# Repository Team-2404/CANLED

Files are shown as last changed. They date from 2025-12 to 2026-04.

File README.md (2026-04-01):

# CANLED
*An open source CAN LED controller for FRC*




> [!NOTE]
> Picture TBD

## Overview

CANLED is an open source LED controller by FRC team 2404 which communicates over the 
CAN protocol. Based on the ATmega328P microcontroller and MCP2515/2561 CAN 
controller/transciever, this project repository includes the parts (`hardware/docs/`),
schematics (`hardware/kicad/`), firmware (`firmware/canled/`), and software (`software/`) 
needed to assemble the controller and use it with wpilib for FRC. By default set up to control LED strips using the WS2812B controller.

An AVR programmer is needed to flash the firmware using the Arduino IDE.

## Flashing firmware

These instructions assume you are using Windows and a generic USBasp AVR programmer such as [this](https://www.amazon.com/HiLetgo-ATMEGA8-Programmer-USBasp-Cable/dp/B00AX4WQ00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). 
First, [install zadig.exe](https://zadig.akeo.ie/). Plug in your programmer, connect the CANLED,
and open zadig. Find the USBasp device in the drop-down menu and select it. Choose the WinUSB driver
on the right side using the arrows and click install. Once the driver is installed, open Arduino IDE.
Open up the canled.ino file in the firmware directory (`firmware/canled`) and open up the "tools" 
drop-down menu. Select Arduino Uno as the board and USBasp as the programmer. Open up the "sketch" 
drop-down menu and select "install using programmer". If there is an error, try unplugging and 
replugging the programmer. 

## Contributors

- @ConorKellyGerakos
- @koshan-dawlaty
- @jakehlee (mentor)

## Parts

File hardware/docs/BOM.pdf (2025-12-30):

Index Manufacturer Name | Description | Manufacturer Part Number Digi-Key Part Number | Quantity
1 Traco Power | DC DC CONVERTER 5V 5W | TSR 1-2450 | 1951-2747-ND | 1
2 Microchip Technology | IC TRANSCEIVER HALF 1/1 8PDIP | MCP2561-H/P | MCP2561-H/P-ND | 1
3 Microchip Technology | IC MCU 8BIT 32KB FLASH 28DIP | ATMEGA328-PU | ATMEGA328-PU-ND | 1
4 Microchip Technology | IC CAN CONTROLLER W/SPI 18DIP | MCP2515-I/P | MCP2515-I/P-ND | 1
5 STMicroelectronics | DIODE SCHOTTKY 30V 1A DO41 | 1N5818 | 497-4548-1-ND | 1
6 Rubycon | CAP ALUM 1000UF 20% 16V RADIAL | 16ZLH1000MEFC10X16 | 1189-1147-ND | 1
7 Würth Elektronik | CONN HEADER VERT 6POS 2.54MM | 61200621621 | 732-5394-ND | 1
8 TE Connectivity AMP Connectors | CONN IC DIP SOCKET 8POS TIN | 1-2199298-2 | A120347-ND | 1
9 TE Connectivity AMP Connectors | CONN IC DIP SOCKET 28POS TIN | 1-2199298-9 | A120353-ND | 1
10 Raltron Electronics | CRYSTAL 16.0000MHZ 18PF TH | AS-16.000-18 | 2151-AS-16.000-18-ND | 1
11 WAGO Corporation | PCB TERMINAL BLOCK; LEVER; 4 MM; | 2604-1103 | 2946-2604-1103-ND | 3
12 WAGO Corporation | PCB TERMINAL BLOCK; LEVER; 4 MM; | 2604-1104 | 2946-2604-1104-ND | 1
13 CNC Tech | CONN IC DIP SOCKET 18POS TIN | 245-18-1-03 | 1175-1489-ND | 1
14 Vishay Beyschlag/Draloric/BC Components CAP CER 0.1UF 50V X7R RADIAL | K104K10X7RF5UH5 | BC2665CT-ND | 4
15 Vishay Beyschlag/Draloric/BC Components CAP CER 1UF 50V X7R RADIAL | K105K20X7RF5UH5 | BC2668CT-ND | 2
16 Vishay Beyschlag/Draloric/BC Components CAP CER 22PF 50V C0G/NP0 RADIAL | K220J10C0GF5UH5 | BC5230CT-ND | 4
17 Citizen Finedevice Co Ltd | CRYSTAL 8.0000MHZ 18PF TH | HC-49/U-S8000000ABJB | 300-6017-ND | 1
18 Same Sky (Formerly CUI Devices) | SWITCH TACTILE SPST-NO 0.05A 12V | TS02-66-55-BK-100-LCR-D 2223-TS02-66-55-BK-100-LCR-D-ND | 1
19 Stackpole Electronics Inc | RES 1K OHM 5% 1/4W AXIAL | CF14JT1K00 | CF14JT1K00CT-ND | 1
20 Stackpole Electronics Inc | RES 10K OHM 5% 1/4W AXIAL | CF14JT10K0 | CF14JT10K0CT-ND | 1
21 Stackpole Electronics Inc | RES 560 OHM 5% 1/4W AXIAL | CF14JT560R | CF14JT560RCT-ND | 2
22 Würth Elektronik | LED BLUE DIFFUSED 5MM ROUND T/H | 151051BS04000 | 732-5015-ND | 1
23 Würth Elektronik | LED GREEN DIFFUSED 5MM ROUND T/H 151051VS04000 | 732-5017-ND | 1
24 Bourns Inc. | FIXED IND 5.6UH 500MA 400MOHM TH | 78F5R6J-RC | 78F5R6J-RC-ND | 1
25 Stackpole Electronics Inc | RES 120 OHM 5% 1/4W AXIAL | CF14JT120R | CF14JT120RCT-ND | 1
26 Harwin Inc. | CONN HEADER VERT 2POS 2.54MM | M20-9990246 | 952-2262-ND | 1
27 Sullins Connector Solutions | CONN JUMPER SHORTING .100" GOLD | QPC02SXGN-RC | S9337-ND | 1

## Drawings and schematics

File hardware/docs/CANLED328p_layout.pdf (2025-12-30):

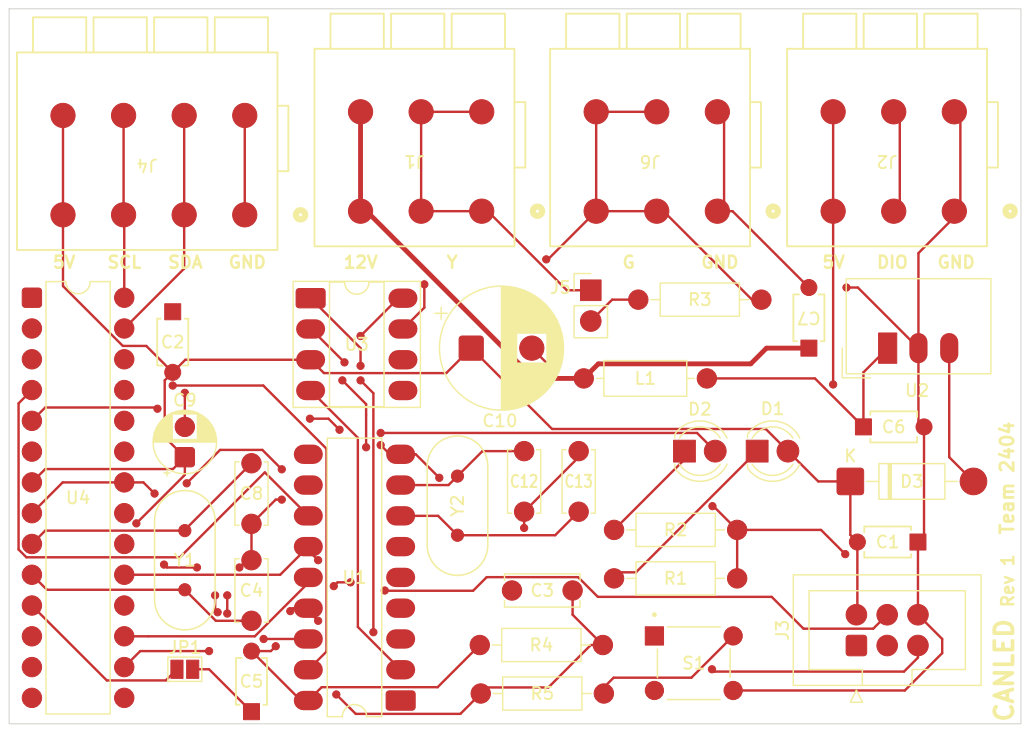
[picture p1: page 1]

Id: 1/2 Title: File: CANLED328p.kicad_pcb Sheet:

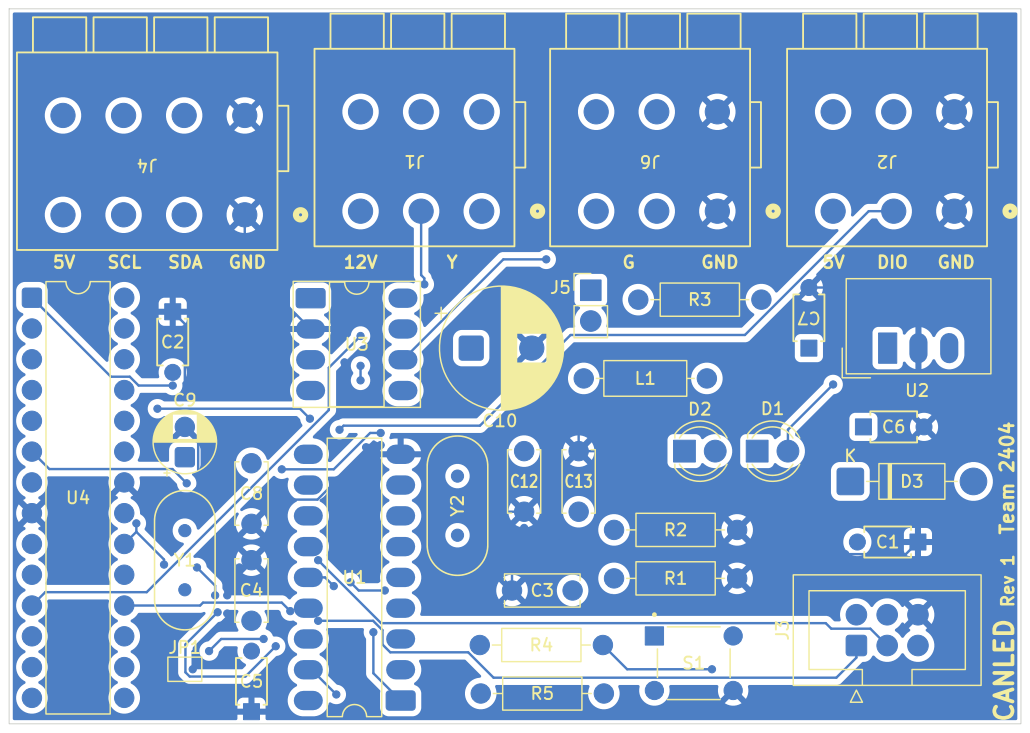
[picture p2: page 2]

Id: 2/2 Title: File: CANLED328p.kicad_pcb Sheet:

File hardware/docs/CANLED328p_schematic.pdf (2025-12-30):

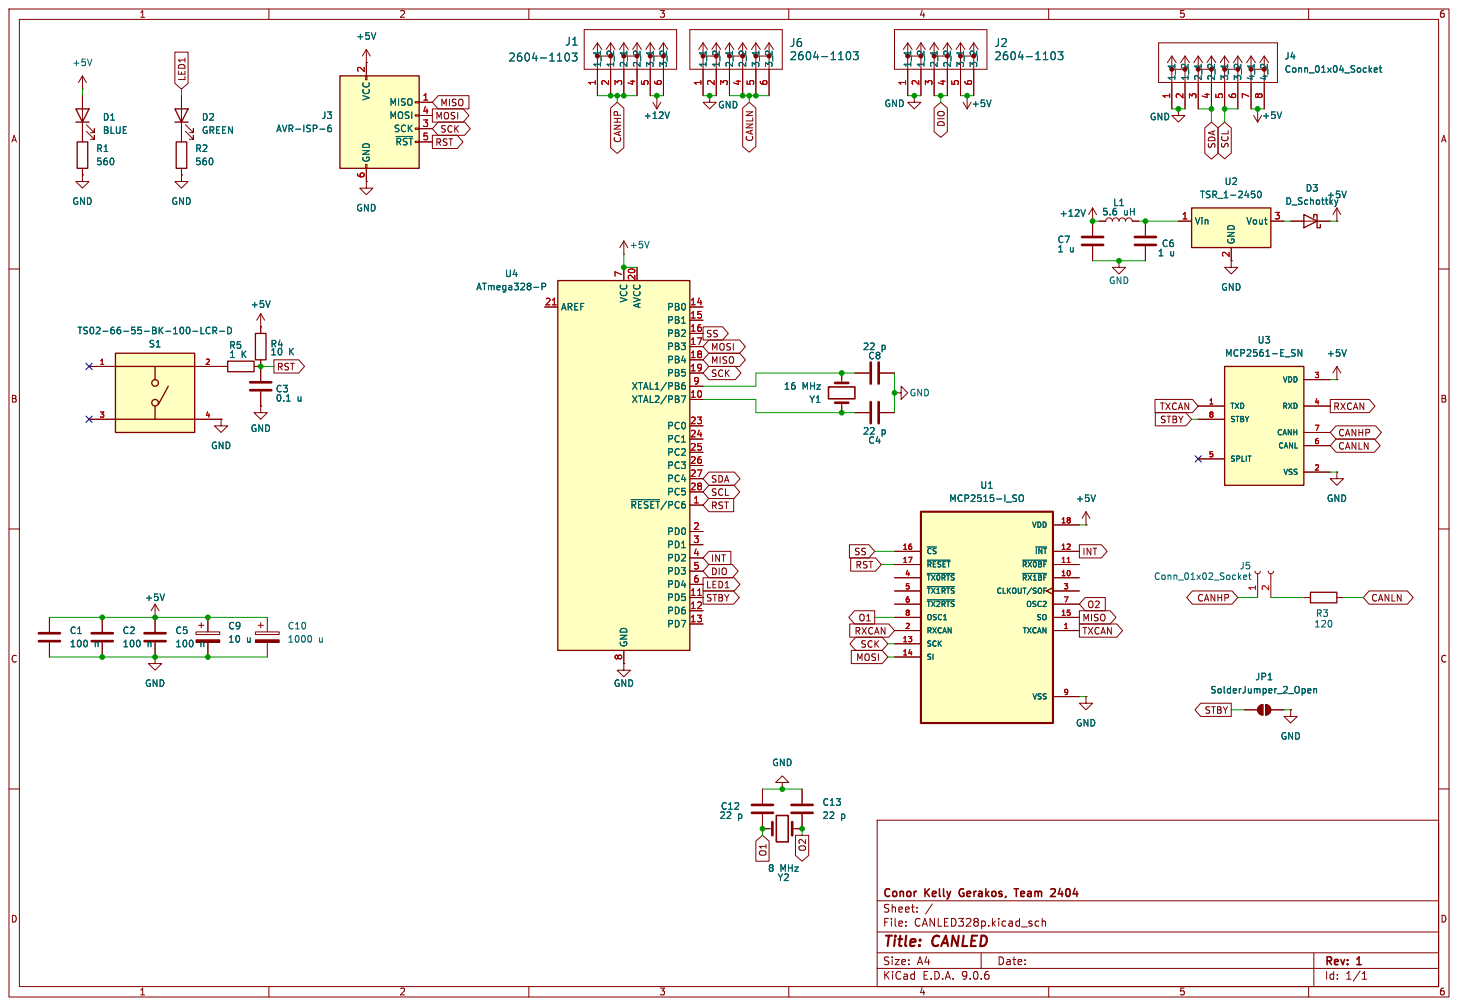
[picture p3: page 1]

6 MISO 1 MOSI 4 SCK 3 ~{RST}5 +5V D2 GREEN

6 MISO 1 MOSI 4 SCK 3 ~{RST}5

8 AVCC 20 PB0 14 PB1 15 PB2 16 PB3 17 PB4 18 PB5 19 XTAL1/PB6 9 XTAL2/PB7 10 PC0 23 PC1 24 PC2 25 PC3 26 PC4 27 PC5 28 ~{RESET}/PC61 PD0 2 PD1 3 PD2 4 PD3 5 PD4 6 PD5 11 PD6 12 PD7 13 U4 ATmega328-P GND GND

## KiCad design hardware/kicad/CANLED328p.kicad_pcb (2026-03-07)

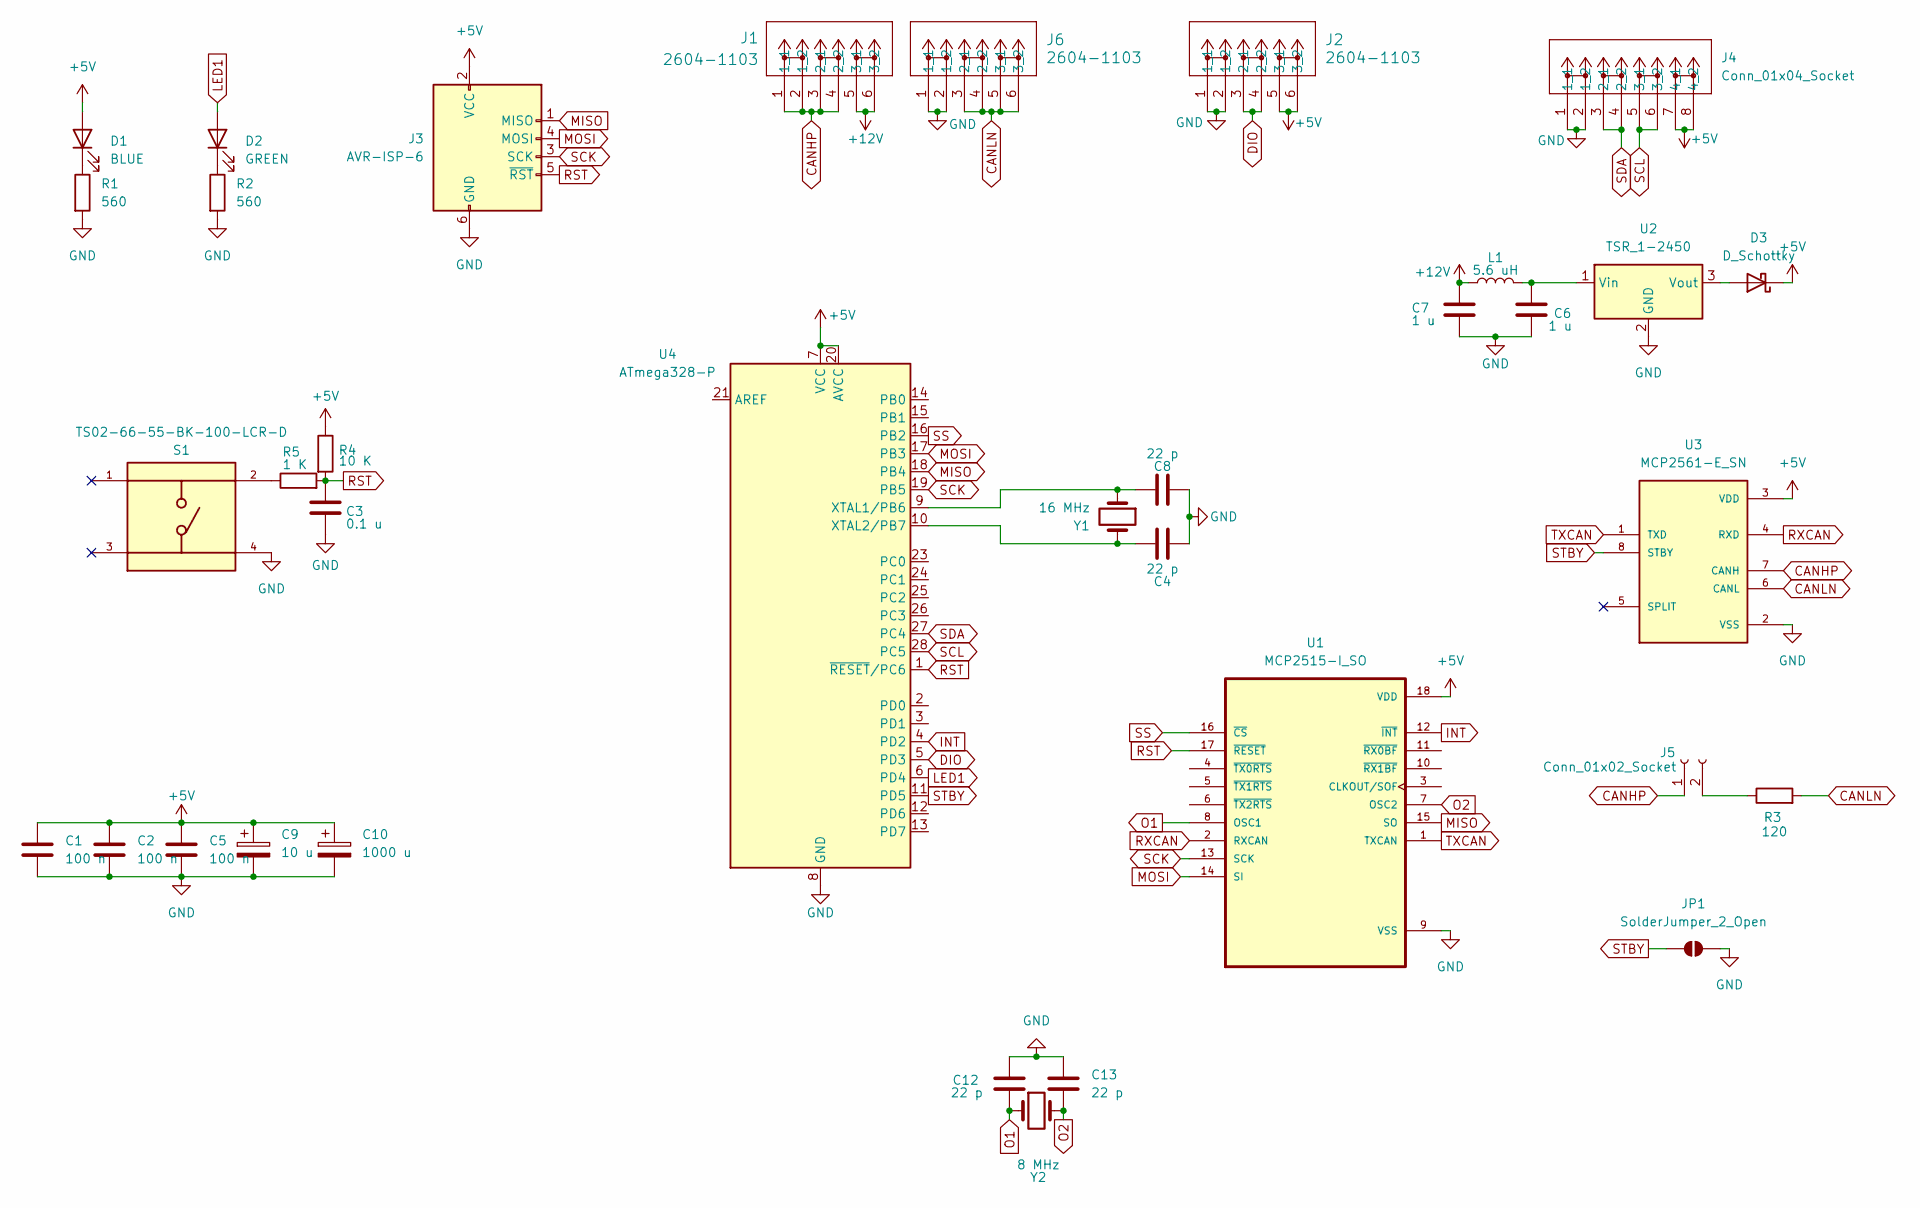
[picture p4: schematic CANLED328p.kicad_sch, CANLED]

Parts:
C1, C2, C5: 100 n; K104K10X7RF5UH5_VIS
C3: 0.1 u; C_Disc_D6.0mm_W2.5mm_P5.00mm
C4, C8, C12, C13: 22 p; C_Disc_D5.0mm_W2.5mm_P5.00mm
C6, C7: 1 u; K104K10X7RF5UH5_VIS
C9: 10 u; CP_Radial_D5.0mm_P2.50mm
C10: 1000 u; CP_Radial_D10.0mm_P5.00mm
D1: BLUE; LED_D4.0mm
D2: GREEN; LED_D4.0mm
D3: D_Schottky; D_DO-41_SOD81_P10.16mm_Horizontal
J1, J2, J6: 2604-1103; CONN3_2604-1103_WAG
J3: AVR-ISP-6; IDC-Header_2x03_P2.54mm_Vertical
J4: Conn_01x04_Socket; CONN4_2604-1104_WAG
J5: Conn_01x02_Socket; PinHeader_1x02_P2.54mm_Vertical
JP1: SolderJumper_2_Open; SolderJumper-2_P1.3mm_Open_Pad1.0x1.5mm
L1: 5.6 uH; L_Axial_L6.6mm_D2.7mm_P10.16mm_Horizontal_Vishay_IM-2
R1, R2: 560; R_Axial_DIN0207_L6.3mm_D2.5mm_P10.16mm_Horizontal
R3: 120; R_Axial_DIN0207_L6.3mm_D2.5mm_P10.16mm_Horizontal
R4: 10 K; R_Axial_DIN0207_L6.3mm_D2.5mm_P10.16mm_Horizontal
R5: 1 K; R_Axial_DIN0207_L6.3mm_D2.5mm_P10.16mm_Horizontal
S1: TS02-66-55-BK-100-LCR-D; SW_TS02-66-55-BK-100-LCR-D; PARTREV 1.0
U1: MCP2515-I_SO; DIP-18_W7.62mm_LongPads
U2: TSR_1-2450; Converter_DCDC_TRACO_TSR-1_THT
U3: MCP2561-E_SN; DIP-8_W7.62mm_Socket_LongPads; PARTREV C
U4: ATmega328-P; DIP-28_W7.62mm
Y1: 16 MHz; XTAL_HC49P488W46L1150T500H350
Y2: 8 MHz; XTAL_HC49P488W46L1150T500H350

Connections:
+5V: C1.2, C2.2, C5.2, C9.1, C10.1, D1.2 (A), D3.1 (K), J2.5 (3_1), J2.6 (3_2), J3.2 (VCC), J4.7 (4_1), J4.8 (4_2), R4.1, U1.18 (VDD), U3.3 (VDD), U4.7 (VCC), U4.20 (AVCC)
+12V: C7.1, J1.5 (3_1), J1.6 (3_2), L1.1
CANHP: J1.1 (1_1), J1.2 (1_2), J1.3 (2_1), J1.4 (2_2), J5.1, U3.7 (CANH)
CANLN: J6.3 (2_1), J6.4 (2_2), J6.5 (3_1), J6.6 (3_2), R3.2, U3.6 (CANL)
DIO: J2.3 (2_1), J2.4 (2_2), U4.5 (PD3)
GND: C1.1, C2.1, C3.2, C4.2, C5.1, C6.2, C7.2, C8.1, C9.2, C10.2, C12.1, C13.1, J2.1 (1_1), J2.2 (1_2), J3.6 (GND), J4.1 (1_1), J4.2 (1_2), J6.1 (1_1), J6.2 (1_2), JP1.2 (B), R1.2, R2.2, S1.4, U1.9 (VSS), U2.2 (GND), U3.2 (VSS), U4.8 (GND), U4.22 (GND)
INT: U1.12 (~INT), U4.4 (PD2)
LED1: D2.2 (A), U4.6 (PD4)
MISO: J3.1 (MISO), U1.15 (SO), U4.18 (PB4)
MOSI: J3.4 (MOSI), U1.14 (SI), U4.17 (PB3)
unnamed: D1.1 (K), R1.1
unnamed: D2.1 (K), R2.1
unnamed: D3.2 (A), U2.3 (Vout)
unnamed: J5.2, R3.1
unnamed: R5.1, S1.2
unnamed: C6.1, L1.2, U2.1 (Vin)
unnamed: C8.2, U4.9 (XTAL1/PB6), Y1.1
unnamed: C4.1, U4.10 (XTAL2/PB7), Y1.2
O1: C12.2, U1.8 (OSC1), Y2.1
O2: C13.2, U1.7 (OSC2), Y2.2
RST: C3.1, J3.5 (~RST), R4.2, R5.2, U1.17 (~RESET), U4.1 (~RESET/PC6)
RXCAN: U1.2 (RXCAN), U3.4 (RXD)
SCK: J3.3 (SCK), U1.13 (SCK), U4.19 (PB5)
SCL: J4.5 (3_1), J4.6 (3_2), U4.28 (PC5)
SDA: J4.3 (2_1), J4.4 (2_2), U4.27 (PC4)
SS: U1.16 (~CS), U4.16 (PB2)
STBY: JP1.1 (A), U3.8 (STBY), U4.11 (PD5)
TXCAN: U1.1 (TXCAN), U3.1 (TXD)

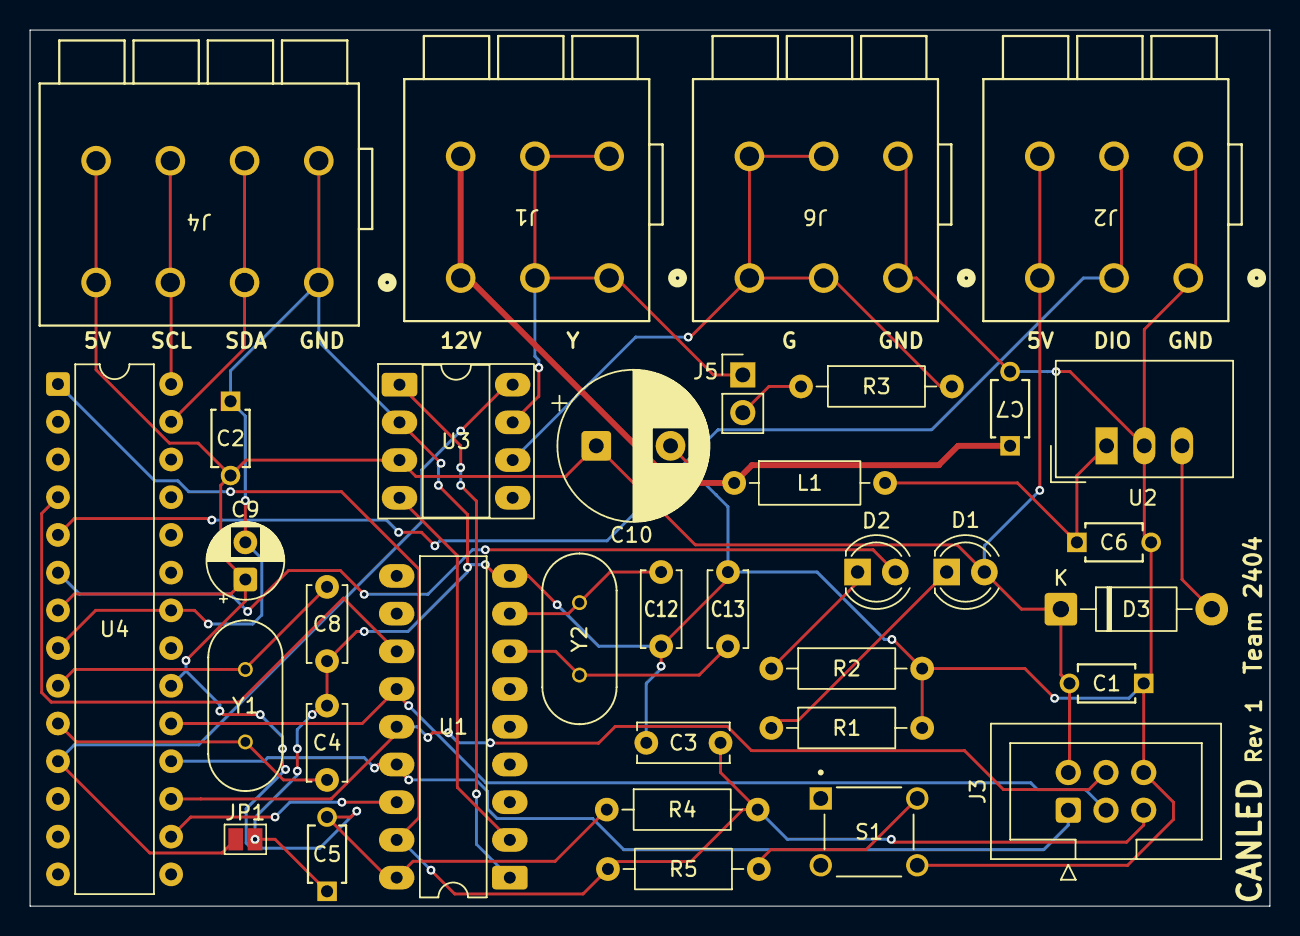
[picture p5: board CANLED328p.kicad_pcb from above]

Board: 2 copper layers, 83.5 x 59.0 mm, 35 parts (0 on the bottom side), 28 nets.

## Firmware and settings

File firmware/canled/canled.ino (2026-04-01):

/*
 * CANLED ATmega328P firmware
 *
 * Authors: Conor Kelly Gerakos, Koshan Dawlaty
 * Team: FRC 2404
 * License: GPL v3.0
 * Year: 2025
 */
#include <mcp_can.h>
#include <SPI.h>
#include <FastLED.h>

// CAN Pins
#define CAN0_CS_PIN    10
#define CAN0_INT_PIN   2

// Board LED Pins
#define LED_DATA_PIN   3
#define LED_OK_PIN     4
#define LED_STATUS_PIN 5

// FRC Device ID
#define DEVICE_ID 55

// FRC Device Type
#define DEVICE_TYPE 10

// FRC Device Manufacturer
#define DEVICE_MFG 8

// ROBORIO Disable ID
#define BROADCAST_DISABLE 0b00000000000000000000000000000

// ROBORIO CAN Heartbeat
#define HEARTBEAT 0b00001000000010001100001000000//0x01011840

// Number of LEDs used in strip -- change if different
#define NUM_LEDS 20//86
// Type of LED controller -- change if different, must be supported by FastLED - see docs: https://github.com/FastLED/FastLED/wiki/Chipset-reference
#define LED_TYPE WS2812B
// Color order for LED strip - not entirely certain what this does, as ordering is strange
#define COLOR_ORDER GRB  // GRB here but actually RGB?

bool teamColorEnableState = false;
long unsigned int rxId;
unsigned char len = 0;
unsigned char rxBuf[8];
char msgString[128];
int mode = 0;
int color[] = { 0, 0, 0 };
byte dir;

struct [[gnu::packed]] RobotState {
  uint64_t matchTimeSeconds : 8;
  uint64_t matchNumber : 10;
  uint64_t replayNumber : 6;
  uint64_t redAlliance : 1;
  uint64_t enabled : 1;
  uint64_t autonomous : 1;
  uint64_t testMode : 1;
  uint64_t systemWatchdog : 1;
  uint64_t tournamentType : 3;
  uint64_t timeOfDay_yr : 6;
  uint64_t timeOfDay_month : 4;
  uint64_t timeOfDay_day : 5;
  uint64_t timeOfDay_sec : 6;
  uint64_t timeOfDay_min : 6;
  uint64_t timeOfDay_hr : 5;
};

MCP_CAN CAN0(CAN0_CS_PIN);
CRGB leds[NUM_LEDS];

struct rainbow_state {
  u8 index;
  const u16 wait;
  const u8 dim;
};

struct solid_rainbow_state {
  u8 color;
};

struct real_rainbow_state {
  u16 color;
};

#define SOLID_RAINBOW_INIT() (struct solid_rainbow_state) {.color = 0}
#define RAINBOW_INIT(_wait, _dim) (struct rainbow_state) {.index = 0, .wait = _wait, .dim = _dim}

struct rainbow_state rainbow_one = RAINBOW_INIT(10, 6);
struct solid_rainbow_state rainbow_two = {0};
struct real_rainbow_state rainbow_three = {0};

void setup() {
  pinMode(CAN0_INT_PIN, INPUT);
  pinMode(LED_OK_PIN, OUTPUT);
  pinMode(LED_STATUS_PIN, OUTPUT);
  digitalWrite(LED_STATUS_PIN, LOW);

  FastLED.addLeds<LED_TYPE, LED_DATA_PIN, COLOR_ORDER>(leds, NUM_LEDS);

  if (CAN0.begin(MCP_EXT, CAN_1000KBPS, MCP_8MHZ) == CAN_OK) {
    //digitalWrite(LED_OK_PIN, HIGH);
  }

  CAN0.init_Mask(0, 1, 0x3F);  // make sure these guys are doing something -- test on prebuilt modules
  CAN0.init_Filt(0, 1, 0x37);  
  CAN0.init_Filt(1, 1, 0x37);
  CAN0.init_Filt(2, 1, 0x37);
  CAN0.init_Filt(3, 1, 0x37);
  CAN0.init_Mask(1, 1, 0b11111111111111111111111111111); // TEST
  CAN0.init_Filt(4, 1, BROADCAST_DISABLE);
  CAN0.init_Filt(5, 1, HEARTBEAT);
  // maybe incorporate other parts of the CAN packet in choosing patterns (API ID)
  CAN0.setMode(MCP_NORMAL);  // Set operation mode to normal so the MCP2515 sends acks to received data.
}

void loop() {
  //rainbow_real(&rainbow_three,15);
  //rainbowCycleSolid(&rainbow_two, 10);
  switch (mode) {
    case 1:
      {
        teamColorEnableState = false;
        fill_solid(leds, NUM_LEDS, CRGB(color[0], color[1], color[2]));
        FastLED.show();
        break;
      }
    case 2:
      {
        teamColorEnableState = false;
        rainbowCycle(&rainbow_one);
        dir = random(0, 2);
        break;
      }
    case 3:
      {
        teamColorEnableState = false;
        rainbowCycleSolid(&rainbow_two, color[0]);
        break;
      }
    case 4:
      {
        teamColorEnableState = false;
        rainbow_real(&rainbow_three, color[0]);
        break;
      }
    case 5:
      {
        teamColorEnableState = true;
        break;
      }
    default:
      {
        break;
      }
  }
  digitalWrite(LED_STATUS_PIN, LOW);

  if (!digitalRead(CAN0_INT_PIN))  // If CAN0_INT_PIN pin is low, read receive buffer
  {
    //digitalWrite(LED_OK_PIN, HIGH);
    CAN0.readMsgBuf(&rxId, &len, rxBuf);  // Read data: len = data length, buf = data byte(s)
    if(rxId == HEARTBEAT){
      fill_solid(leds, NUM_LEDS, CRGB(10,200,10));
      FastLED.show();
      digitalWrite(LED_OK_PIN, HIGH);
    }
    if(rxId == HEARTBEAT && teamColorEnableState){
      struct RobotState* state = (RobotState*)rxBuf;
      if((rxBuf[4] & (1 << 7)) != 0){
        fill_solid(leds, NUM_LEDS, CRGB(230,10,10));
      }else{
        fill_solid(leds, NUM_LEDS, CRGB(10,10,230));
      }
      FastLED.show();
      FastLED.delay(10);
    }
    if(rxId == BROADCAST_DISABLE && false) // TEST
    {
      while(1)
      {
        CAN0.readMsgBuf(&rxId, &len, rxBuf);
        if(rxId == HEARTBEAT && ((rxBuf[4]&&00000010)==1)){ // TEST
          loop();
        }
        delay(20);
      }; // Disables device to comply with FRC CAN spec. Will re-enable upon detecting set 'enabled' bit in CAN heartbeat.
    }

    if ((rxId & 0x3F) == DEVICE_ID) {
      mode = rxBuf[0];
      if (mode == 1) {
        color[0] = rxBuf[1];  // probably a more elegant way to do this -  make sure ordering is correct?
        color[1] = rxBuf[2];
        color[2] = rxBuf[3];
      }
    }
  }
  delay(10);  // is this delay necessary? should it be shorter?
}

// MODIFIED FROM https://github.com/leon-anavi/arduino-fastled-rainbow/blob/master/fastled_rainbow/fastled_rainbow.ino

void rainbowCycle(struct rainbow_state* state) {
  //loop through all colors in the wheel
  state->index++;
  // if (state->index < 0) {
  //   state->index = 255;
  // }

  //Set RGB color of each LED
  for (int i = 0; i < NUM_LEDS; i++) {
    CRGB ledColor = wheel(((i * 256 / NUM_LEDS) + state->index) % 256, state->dim);
    leds[i] = ledColor;
  }

  FastLED.show();
  FastLED.delay(state->wait);
}


CRGB wheel(int WheelPos, int dim) {
//   CRGB color;  // orgininally R G B ordering
//   if (85 > WheelPos) {
//     color.b = 0;
//     color.g = WheelPos * 3 / dim;
//     color.r = (255 - WheelPos * 3) / dim;
//   } else if (170 > WheelPos) {
//     color.b = WheelPos * 3 / dim;
//     color.g = (255 - WheelPos * 3) / dim;
//     color.r = 0;
//   } else {
//     color.b = (255 - WheelPos * 3) / dim;
//     color.g = 0;
//     color.r = WheelPos * 3 / dim;  // *3
//   }
//   return color;
 CRGB color;
  if (85 > WheelPos)
  {
   color.r=0;
   color.g=WheelPos * 3/dim;
   color.b=(255 - WheelPos * 3)/dim;;
  } 
  else if (170 > WheelPos)
  {
   color.r=WheelPos * 3/dim;
   color.g=(255 - WheelPos * 3)/dim;
   color.b=0;
  }
  else
  {
   color.r=(255 - WheelPos * 3)/dim;
   color.g=0;
   color.b=WheelPos * 3/dim;
  }
  return color;
 }


void rainbowCycleSolid(struct solid_rainbow_state* state, u8 wait) {
  struct CHSV hsv = CHSV(state->color, 255, 255);

  /* TODO: i dont know what the difference between the conversion functions are */
  //hsv2rgb_rainbow(&hsv, leds, NUM_LEDS);
  for(int i = 0; i<NUM_LEDS;i++){
    leds[i].setHSV(state->color,255,225);
    if(255-state->color<10){
      leds[i].setHSV(state->color,255,225);
    }
    
  }
  FastLED.show();
  FastLED.delay(wait);
  state->color++;
  //fill_solid(leds, NUM_LEDS, c);
  
  // state->num_color++;
  // if (state->num_color == 0) {
  //   state->num_color = 0;

  //   state->decrease++;
  //   if (state->decrease > 3) {
  //     state->decrease = 0;
  //   }

  //   state->increase = state->decrease == 2 ? 0 : state->decrease + 1;
  // }

  // state->color[state->decrease]--;
  // state->color[state->increase]++;

  // fill_solid(leds, NUM_LEDS, CRGB(state->color[0], state->color[1], state->color[2]));

  // FastLED.show();
  // FastLED.delay(state->wait);
}

void rainbow_real(struct real_rainbow_state* state, u8 wait){
  state->color++;
  for(int i = 0; i<NUM_LEDS;i++){
    leds[i].setHSV(i * 255 / NUM_LEDS,255,255);//state->color+(2*i)
  }
  FastLED.show();
  FastLED.delay(wait);
}

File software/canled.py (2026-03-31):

"""
CANLED WPILIB Python API

Author: Conor Kelly Gerakos
Team: FRC 2404
License: GPL v3.0
Year: 2025
"""

import wpilib

class CANLED:
    """A class for controlling the CANLED board."""
    def __init__(self, can_id: int):
        self.can_id = can_id
        self.device = wpilib.CAN(can_id)
        self.api_id = 0b01010000010000000000000000000 + can_id
        self.wavenum = 4
        self.solidnum = 3
        self.alliancenum = 5

    def solid_color(self, red : int, green : int, blue : int):
        """Sets all LEDs to a solid color"""
        color = [1, red, green, blue]
        self.device.writePacket(color[0].to_bytes()+color[1].to_bytes()+color[2].to_bytes()+color[3].to_bytes(), self.api_id)

    def rainbow_cycle(self, wait = 10):
        """Rainbow 'wave' of sorts. Waits for (wait) ms during loop."""
        # colors need to be fixed
        self.device.writePacket((self.wavenum).to_bytes()+wait.to_bytes(), self.api_id)

    def rainbow_solid(self, wait = 10):
        """All LEDs cycle through the same colors. Waits for (wait) ms during loop."""
        # currently acts strangely
        self.device.writePacket((self.solidnum).to_bytes()+(wait).to_bytes, self.api_id)
    
    def use_alliance_color(self):
        """Sets all LEDs to the alliance(red/blue) color set in the robot."""
        self.device.writePacket((self.alliancenum).to_bytes(), self.api_id)

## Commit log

2025-05-12 previous work added
    [CAN-RGB-1.kicad_pcb, CAN-RGB-1.kicad_sch]
2025-05-13 reset and labels added
    [CAN-RGB-1.kicad_sch]
2025-06-08 schematic almost finished. 2551->61,pins and power supply
    [CAN-RGB-1.kicad_sch]
2025-06-11 more footprints added, schematic needs review
    [CAN-RGB-1.kicad_sch]
2025-06-13 Beginnings of PCB layout, needs to be reviewed, organized, and finalized.
    [CAN-RGB-1.kicad_pcb, CAN-RGB-1.kicad_sch]
2025-06-26 Layout connections mostly complete
    [CAN-RGB-1.kicad_pcb]
2025-08-25 all work from past month, board rev1
    [CAN-RGB-1.kicad_pcb, CAN-RGB-1.kicad_sch]
2025-09-03 rev1 with some fixes
    [CANLED328p.kicad_pcb, CANLED328p.kicad_sch]
2025-09-24 Beginning of rev1 redesign - major error fixed
    [CANLED328p.kicad_pcb, CANLED328p.kicad_sch]
2025-09-25 schematic cleaned up, new footprints req
    [CANLED328p.kicad_pcb, CANLED328p.kicad_sch]
2025-11-11 Arduino code added
2025-12-09 New arduino code
2025-12-09 Issue fixed w/ py lib
    [canled.py]
2025-12-11 arduino code finalized for release, colors fixed
    [canled.ino]
2025-12-13 old files removed
    [CANLED328p.kicad_sch]
2025-12-13 files fully sorted
    [CANLED328p.kicad_pcb, CANLED328p.kicad_sch]
2025-12-13 added BOM for digikey
    [BOM.xlsx]
2025-12-30 Replaced BOM with simplified CSV This file is visible from GitHub and works with Digikey's Upload a List feature.
    [BOM.csv, BOM.xlsx]
2025-12-30 Reorganization and firmware refactor
    [BOM.csv, CANLED328p.kicad_pcb, CANLED328p.kicad_sch]
2025-12-30 Minor bugfixes and refactor. Commented out placeholder (?) python funcs
    [canled.py]
2025-12-30 Added Kicad plots of board
2026-03-07 Library added, files updated to use library
    [CANLED328p.kicad_pcb]
2026-03-31 can now have LEDs automatically set to alliance color
